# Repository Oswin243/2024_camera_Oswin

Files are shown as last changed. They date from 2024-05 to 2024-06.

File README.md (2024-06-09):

# 2024_camera_Oswin
## Vidéo 

https://github.com/Oswin243/2024_camera_Oswin/assets/166718391/0ddc3cbc-4c59-40dc-9dcf-1f61af386e99

### Table de matie des matières
 [lien fabricaton PCB](https://oshwlab.com/oswin03/sch-ma-cam-ra) 

- [Introduction](#Introduction)
- [Le schéma bloc](#Le-schéma-bloc) 
- [Les caractéristiques](#Les-caractéristiques)
- [Le schéma de principe de la caméra](#Le-schéma-de-principe-de-la-caméra)
  - [Le routage et sérigraphie du PCB](#Le-routage-et-sérigraphie-du-PCB)
- [Bibliothèques nécessaires](#Bibliothèques-nécessaires)  
- [Partie mécanique](#Partie-mécanique)
- 

## Introduction

Pour le cadre de mon projet de fin d’études, j’ai décidé de concevoir une caméra de surveillance connectée, une idée qui m’est venue après avoir visionné des vidéos sur la chaîne [YouTube de Max Imagination](https://www.youtube.com/watch?v=Ul0h5Maeoeg&t=4s). Cette caméra sera en mesure de se déplacer de haut en bas et de droite à gauche avec à des servomoteurs, de filmer tout ce qui se trouve dans son champ de vision. Elle sera également capable de détecter une intrusion avec à des capteurs infrarouges. De plus, la caméra pourra réagir aux mouvements dans son champ de vision, de jour comme de nuit, grâce à des LED infrarouges.
Ce projet représente ma passion pour la technologie et mon engagement envers ce domaine. 
J’ai choisi ce projet par passion pour la technologie de surveillance et les robots.
Ce projet reflète ma passion pour la technologie de surveillance, les robots, et la mécanique, ainsi que mon engagement envers ces domaines. Tout au long de mon parcours scolaire, j’ai acquis des connaissances solides dans ces domaines et j’ai su démontrer ma capacité à résoudre des problèmes.
C’est avec plaisir que je choisis ce projet, car il représente pour moi la fin d’un long parcours scolaire.

## Le schéma bloc



Explication du schéma bloc 

Alimentation : l’alimentation est l’élément vital de l’ensemble du projet, fournissant l’énergie nécessaire à son fonctionnement.

Capteur infrarouge, gauche, droite : capte les mouvements dans son champ d’action, à gauche et à droite.

PCF8574 : Apporte des entrées supplémentaires. 

ESP32 : le « cerveau » du système, l’ESP32 traite, transmet et reçoit toutes les informations nécessaires au fonctionnement du programme.

Smartphone : permets de visualiser le flux vidéo grâce à une connexion Wi-Fi.

PCA9685 : Apporte des sorties supplémentaire et genre nativement du PWM.

LED rouge : indique l’activité de la caméra, signalant ainsi son fonctionnement.

LED infrarouge, gauche, droite : émettre des infrarouges pour voir dans l’obscurité.

Servomoteur x, y : ils permettent d’effectuer des rotations de haut en bas et de gauche à droite, contrôlant ainsi la direction de la caméra

## Les caractéristiques

Caractéristique générale   

•	M5Stack ESP32 Timer Camera 
•	Capteur infrarouge
•	Servomoteurs   
•	LED infrarouge 
•	Resistance 
•	Condensateur 
•	LED 
•	Interrupteur 
•	Transistor
•	Porte fusible   
  
Caractéristique électrique

•	Alimentation : sur secteur  
•	Consommation : pas vérifié  
 
Caractéristique mécanique 

•	Dimension : 218 mm x  238,99 mm  
•	Poids : 851 g 
•	Matériau : PLA (acide polylactique) 

## Le schéma de principe de la caméra



M5stack timer-caméra/ Transistor BS170 /Servomoteur MG996r/ PCF8574/ PCA9685

## Le routage et sérigraphie du PCB

   

[Lien du schéma vers EasyEDA](https://oshwlab.com/oswin03/sch-ma-cam-ra) 

60 mm x 60 mm

## Bibliothèques nécessaires 

Bibliothèques nécessaires pour intégrer les microcontrôleurs ESP32 : 
https://m5stack.oss-cn-shenzhen.aliyuncs.com/resource/arduino/package_m5stack_index.json                                                                               https://raw.githubusercontent.com/espressif/arduino-esp32/gh-pages/package_esp32_index.json 

## Partie mécanique





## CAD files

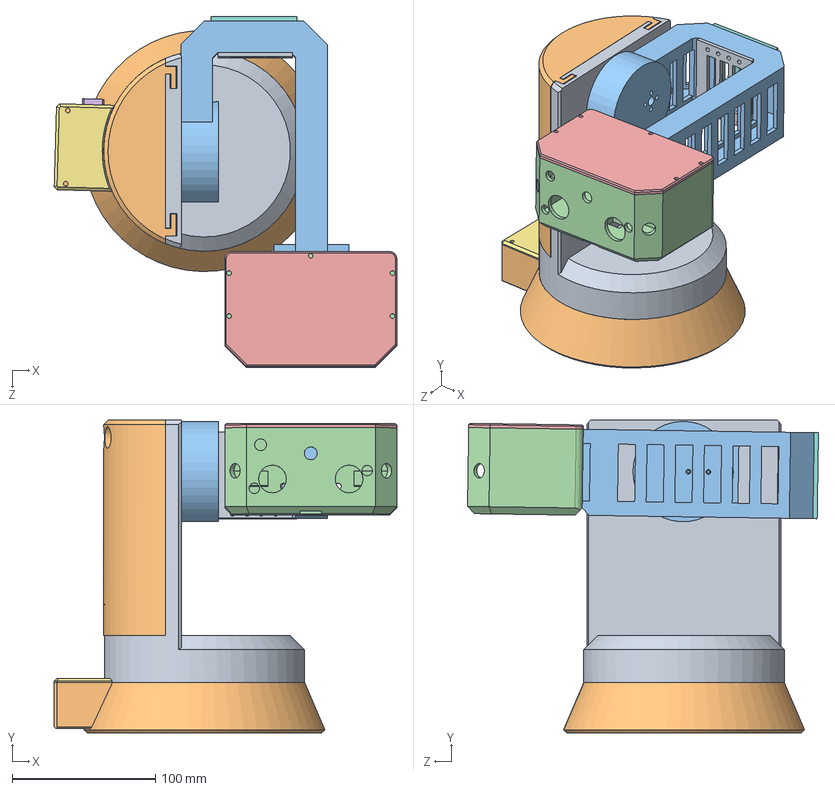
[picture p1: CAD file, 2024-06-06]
Dessin technique/Assemblage_1.SLDASM
239.0 x 218.0 x 244.8 mm
Pièce de haut corrigé
Base caméra
User Library-Futaba-Parallax-ContinuousRatationServo x 2
User Library-Futaba-Servo-X-Horn x 2
PCB caméra (seulement carte)
Connecteur JST-4P
Connecteur JST-3P
Connecteur JST-2P
Connecteur JST-3P - Copie (0)
Connecteur JST-3P - Copie (2)
Connecteur JST-3P - Copie (3)
Connecteur JST-3P - Copie (4)
Connecteur JST-3P - Copie (5)
Connecteur JST-3P - Copie (6)
Connecteur JST-3P - Copie (7)
Connecteur JST-3P - Copie (8)
Connecteur JST-3P - Copie (9)
Connecteur JST-2P - Copie (0)
Connecteur JST-2P - Copie (1)
Condensateur 10v 1000uf
Transistor
Transistor - Copie (0)
Transistor - Copie (1)
User Library-RES_1206L_RES_1206_Lead_1_Default_1 x 6
User Library-RES_1206L_RES_1206_Body_1_1 x 3
Couverture PCB corrigé
boite camera corrigé
tête camera corrigé
couverture camera
cache USB
couverture alimentation
couverture 1
couverture 2

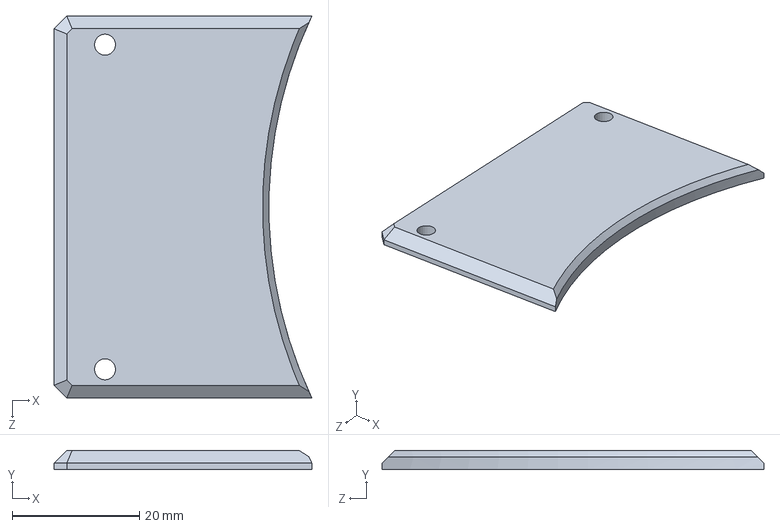
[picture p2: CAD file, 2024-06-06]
Dessin technique/couverture alimentation.SLDPRT
40.5 x 3.00 x 60.0 mm

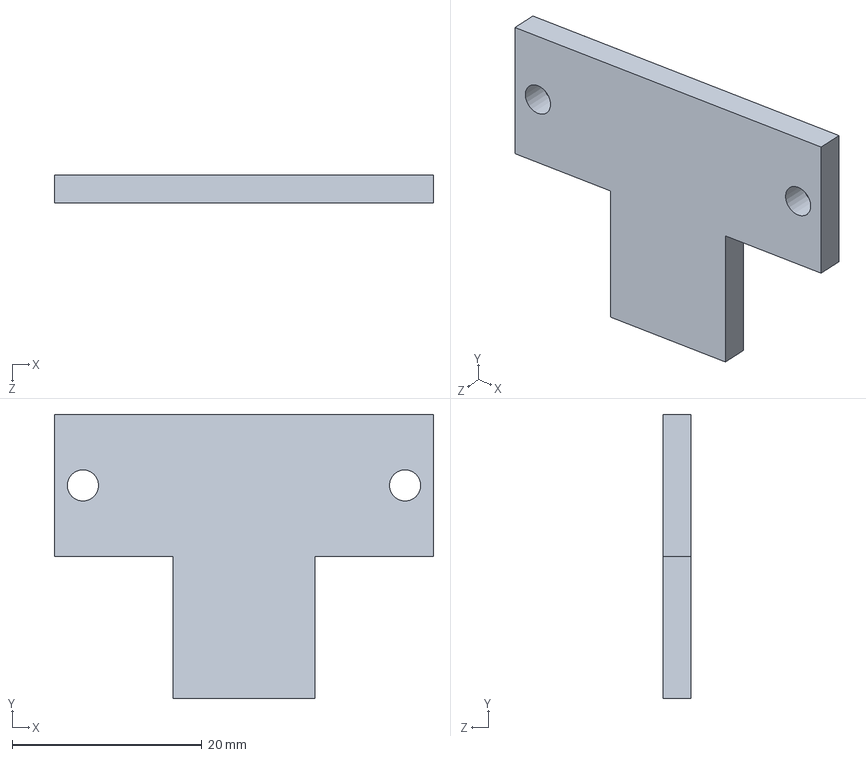
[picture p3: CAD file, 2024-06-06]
Dessin technique/cache caméra.SLDPRT
40.0 x 30.0 x 3.00 mm

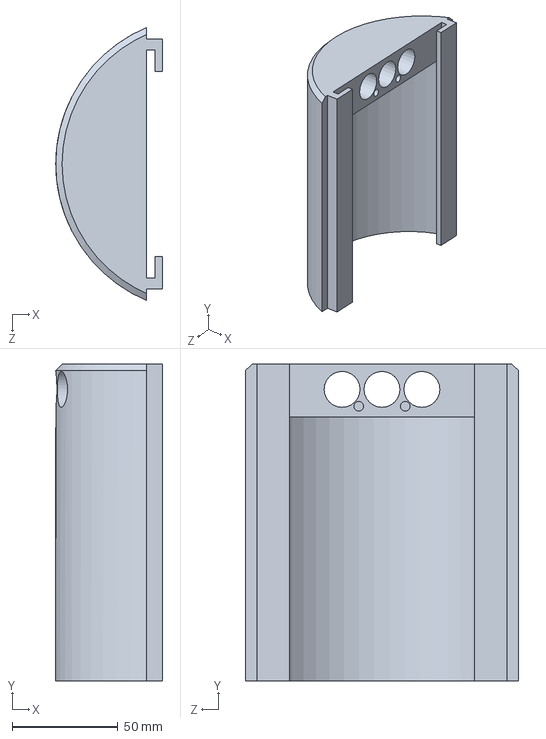
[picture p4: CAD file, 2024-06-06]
Dessin technique/Couverture PCB 1.SLDPRT
50.4 x 150.0 x 129.2 mm

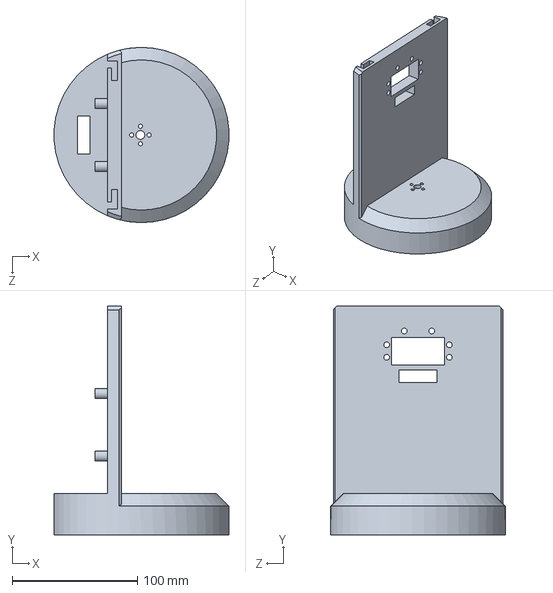
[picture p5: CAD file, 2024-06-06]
Dessin technique/Pièce de haut 1.SLDPRT
139.7 x 183.0 x 140.0 mm

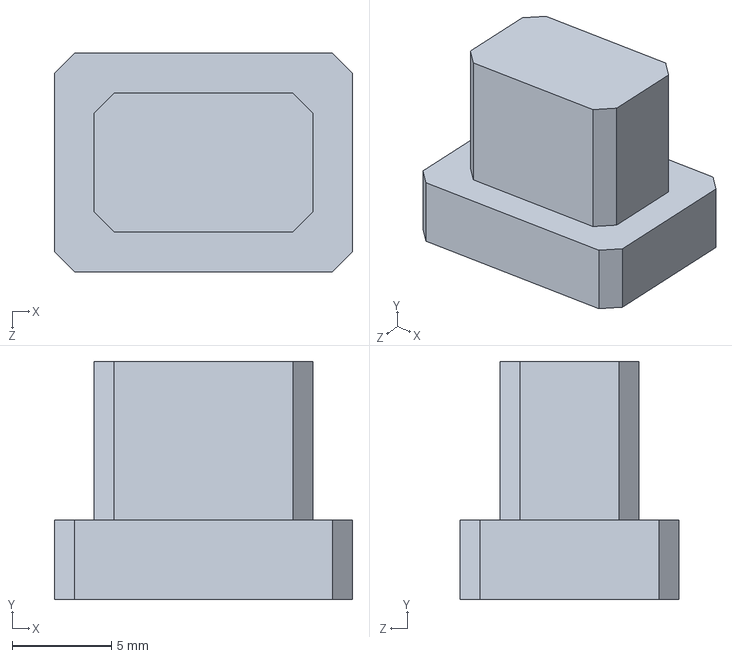
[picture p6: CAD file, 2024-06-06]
Dessin technique/Bouchon.SLDPRT
15.0 x 12.0 x 11.0 mm

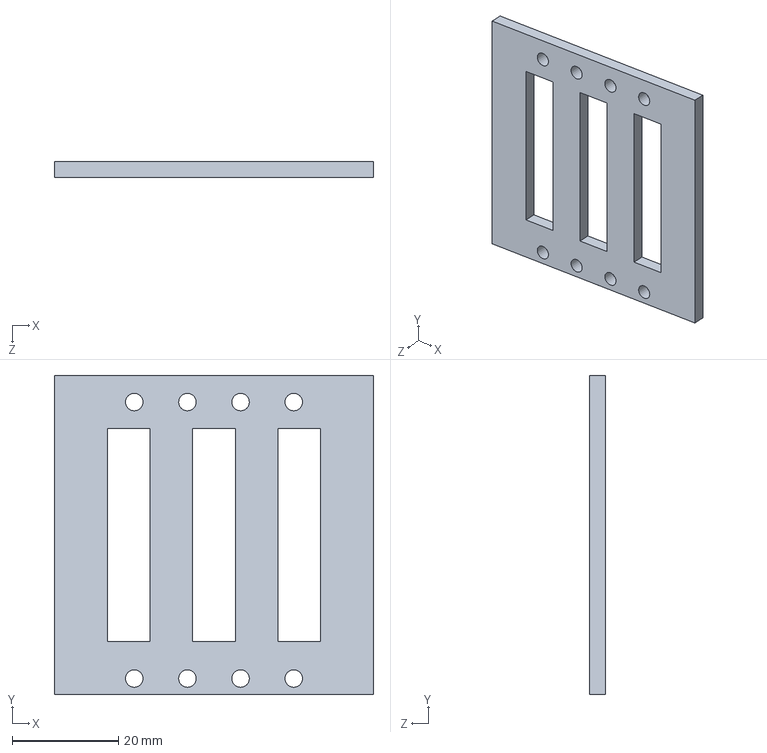
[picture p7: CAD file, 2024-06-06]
Dessin technique/couverture 1.SLDPRT
60.0 x 60.0 x 3.00 mm

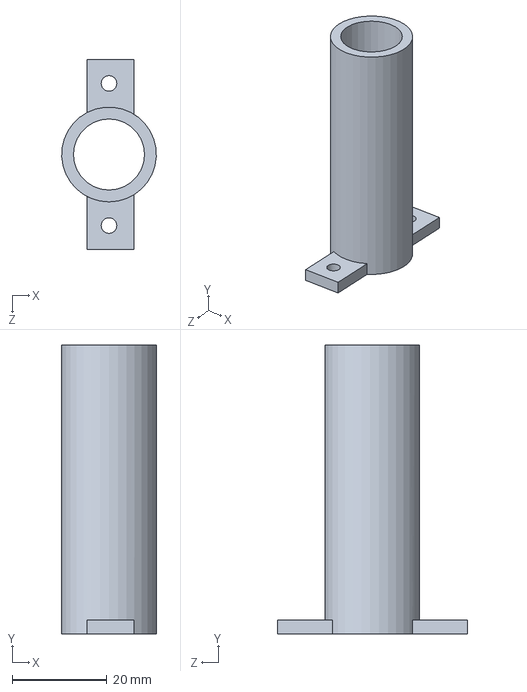
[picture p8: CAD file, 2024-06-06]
Dessin technique/oeillères.SLDPRT
20.0 x 61.0 x 40.0 mm

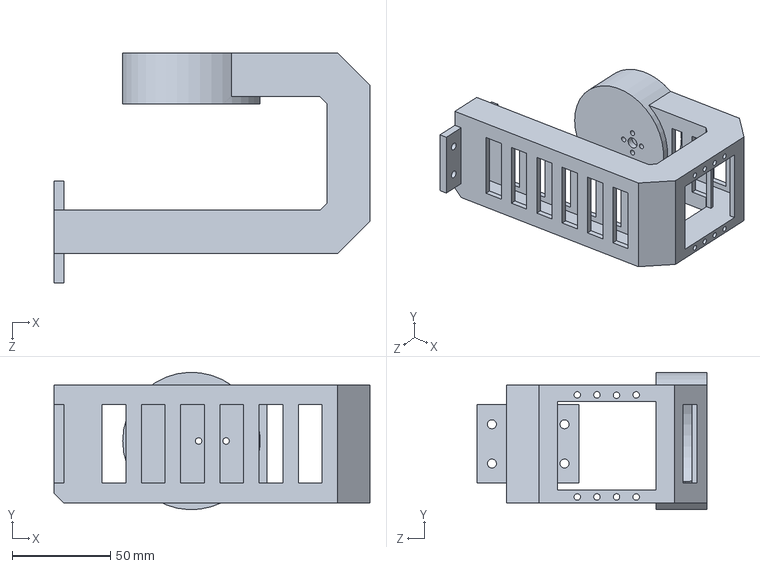
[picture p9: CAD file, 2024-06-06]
Dessin technique/boite camera 1.SLDPRT
161.0 x 69.9 x 117.0 mm

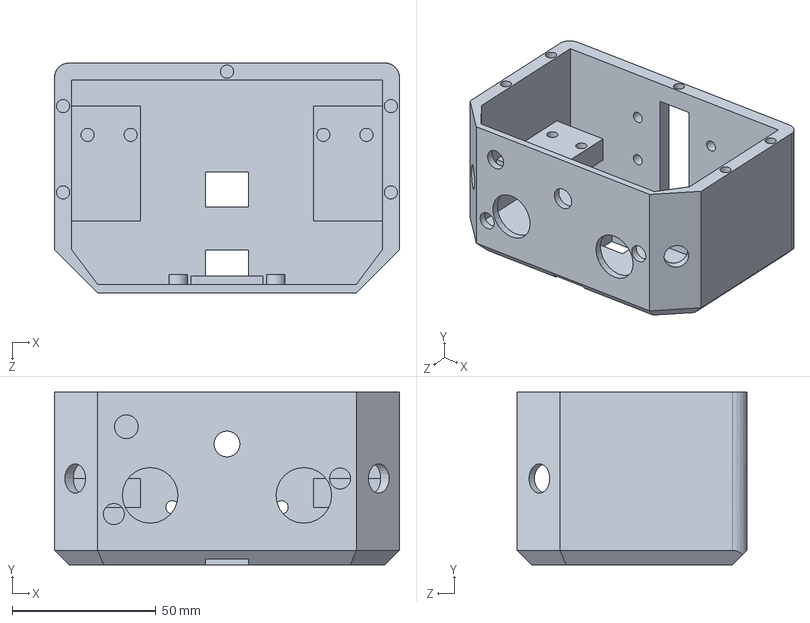
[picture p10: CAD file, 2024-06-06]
Dessin technique/tête camera 1.SLDPRT
120.0 x 60.0 x 80.0 mm

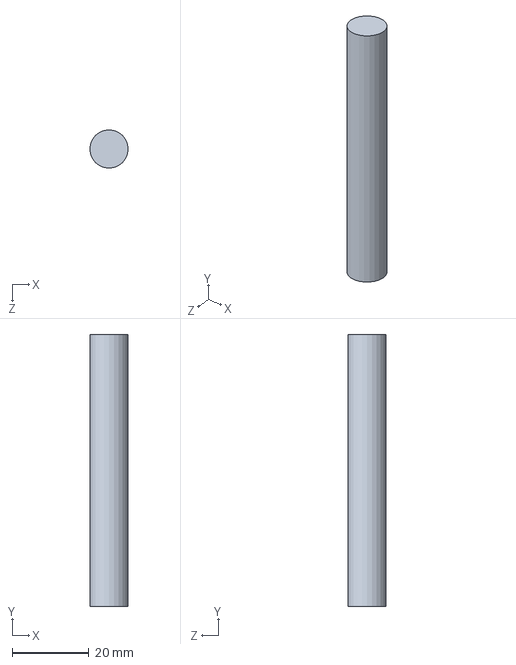
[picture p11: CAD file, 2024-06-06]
Dessin technique/Support led_infra.SLDPRT
10.0 x 71.0 x 10.0 mm

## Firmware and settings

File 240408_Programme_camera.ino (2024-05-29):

/*****************************************Caméra*****************************************
 Caméra connectée
 Kanema Oswin 
 6ème Electronique Inraci (Institut national de radioélectricité et cinématographie)
 Hardware: M5Stack-Timer-CAM; visionnage + PCA9685; i2c (pwm) entrées/sorties supplémentaire + PCF8574 entrées/sorties supplémentaire + servomoteur mg996r
 
*****************************************librairies**************************************/

#include "esp_camera.h"
#include <WiFi.h>
#include <Wire.h>
#include "FaBoPWM_PCA9685.h"
#include "Arduino.h"
#include "PCF8575.h"
#define CAMERA_MODEL_M5STACK_UNITCAM  // ne peut être deplacé
#include "camera_pins.h"

/*****************************************Constante**************************************/
//#define CAMERA_MODEL_M5STACK_UNITCAM
#define P0 0
#define P1 1
#define MAX_VALUE 480
#define MIN_VALUE 80
#define MIN_ANGLE 0    // Angle minimum (en degrés)
#define MAX_ANGLE 180  // Angle maximum (en degrés)
PCF8575 pcf8575(0x20);

/*****************************************Variable**************************************/

FaBoPWM faboPWM;
esp_timer_handle_t timer;
unsigned long timeElapsed;
//const char *ssid     = "KAIROS";
//const char *password = "0487371190";
//const char *ssid     = "INRACI_4G";
//const char *password = "Students-INRaCi";
const char* ssid = "#LaboD5";  //ok
const char* password = "0123456789";
//const char* ssid = "Wifi1";
//const char* password = "6qp7W7n2FEtT";
//const char *ssid     = "iPhone de Oswin";
//const char *password = "Dragon200";
int angle_actuel = 90;
int pulseWidth;

/*****************************************Fonctions***************************************/
void setupLedFlash(int pin);
void startCameraServer();
void IRAM_ATTR onTimer(void* param) {
  static int cpt = 0;
}
int calcul_signal(int angle) {
  return (angle * (MAX_VALUE - MIN_VALUE) / MAX_ANGLE) + MIN_VALUE;  // Calcul de la largeur d'impulsion PWM
}

/*****************************************Intialisation***********************************/
void setup() {
  Wire.begin();
  Serial.begin(115200);
  Serial.setDebugOutput(true);
  Serial.println();
  pcf8575.pinMode(P0, INPUT);
  pcf8575.pinMode(P1, INPUT);
  pcf8575.begin();
  if (faboPWM.begin()) {  // vérification
    Serial.println("Find PCA9685");
    faboPWM.init(300);
  }
  faboPWM.set_hz(50);

  camera_config_t config;
  config.ledc_channel = LEDC_CHANNEL_0;
  config.ledc_timer = LEDC_TIMER_0;
  config.pin_d0 = Y2_GPIO_NUM;
  config.pin_d1 = Y3_GPIO_NUM;
  config.pin_d2 = Y4_GPIO_NUM;
  config.pin_d3 = Y5_GPIO_NUM;
  config.pin_d4 = Y6_GPIO_NUM;
  config.pin_d5 = Y7_GPIO_NUM;
  config.pin_d6 = Y8_GPIO_NUM;
  config.pin_d7 = Y9_GPIO_NUM;
  config.pin_xclk = XCLK_GPIO_NUM;
  config.pin_pclk = PCLK_GPIO_NUM;
  config.pin_vsync = VSYNC_GPIO_NUM;
  config.pin_href = HREF_GPIO_NUM;
  config.pin_sccb_sda = SIOD_GPIO_NUM;
  config.pin_sccb_scl = SIOC_GPIO_NUM;
  config.pin_pwdn = PWDN_GPIO_NUM;
  config.pin_reset = RESET_GPIO_NUM;
  config.xclk_freq_hz = 20000000;
  config.frame_size = FRAMESIZE_UXGA;
  config.pixel_format = PIXFORMAT_JPEG;
  config.grab_mode = CAMERA_GRAB_WHEN_EMPTY;
  config.fb_location = CAMERA_FB_IN_PSRAM;
  config.jpeg_quality = 12;
  config.fb_count = 1;

  if (config.pixel_format == PIXFORMAT_JPEG) {
    if (psramFound()) {
      config.jpeg_quality = 10;
      config.fb_count = 2;
      config.grab_mode = CAMERA_GRAB_LATEST;
    } else {
      config.frame_size = FRAMESIZE_SVGA;
      config.fb_location = CAMERA_FB_IN_DRAM;
    }
  } else {
    config.frame_size = FRAMESIZE_240X240;
#if CONFIG_IDF_TARGET_ESP32S3
    config.fb_count = 2;
#endif
  }

#if defined(CAMERA_MODEL_ESP_EYE)
  pinMode(13, INPUT_PULLUP);
  pinMode(14, INPUT_PULLUP);
#endif

  esp_err_t err = esp_camera_init(&config);
  if (err != ESP_OK) {
    Serial.printf("Camera init failed with error 0x%x", err);
    return;
  }

  sensor_t* s = esp_camera_sensor_get();
  if (s->id.PID == OV3660_PID) {
    s->set_vflip(s, 1);
    s->set_brightness(s, 1);
    s->set_saturation(s, -2);
  }
  if (config.pixel_format == PIXFORMAT_JPEG) {
    s->set_framesize(s, FRAMESIZE_QVGA);
  }

#if defined(CAMERA_MODEL_M5STACK_WIDE) || defined(CAMERA_MODEL_M5STACK_ESP32CAM)
  s->set_vflip(s, 1);
  s->set_hmirror(s, 1);
#endif

#if defined(CAMERA_MODEL_ESP32S3_EYE)
  s->set_vflip(s, 1);
#endif

#if defined(LED_GPIO_NUM)
  setupLedFlash(LED_GPIO_NUM);
#endif

  WiFi.begin(ssid, password);
  WiFi.setSleep(false);

  while (WiFi.status() != WL_CONNECTED) {
    delay(500);
    Serial.print(".");
  }
  Serial.println("");
  Serial.println("WiFi connected");

  startCameraServer();

  Serial.print("Camera Ready! Use 'http://");
  Serial.print(WiFi.localIP());
  Serial.println("' to connect");
  int angle = 0;
  int pulseWidth = calcul_signal(angle);
  faboPWM.set_channel_value(0, pulseWidth);  // servomoteur axe Y(haut/bas)
  int ServoX = 90;
  int PWM = calcul_signal(ServoX);
  faboPWM.set_channel_value(1, PWM);  //servomoteur axe X (gauche/droite)

  faboPWM.set_channel_value(1, calcul_signal(angle_actuel));
}
/*****************************************Boucle**************************************/
void loop() {
  faboPWM.set_channel_value(2, 1500);          // led U11
  faboPWM.set_channel_value(3, 4095);          // infra.led  U13
  faboPWM.set_channel_value(4, 4095);          // infra.led  U15
  uint8_t CapteurD = pcf8575.digitalRead(P0);  // P0=U4  capteur infrarouge droite
  uint8_t CapteurG = pcf8575.digitalRead(P1);  // P1=U5  capteur infrarouge gauche
/*
  Serial.print(CapteurG);
  Serial.print("     ");
  Serial.println(CapteurD);
  delay(300);
*/
  if (CapteurD == 1) {
    Serial.println("HUMAIN a droite");
    for (int angle = angle_actuel; angle >= 33; angle--) {
      faboPWM.set_channel_value(1, calcul_signal(angle));  // U9 servomoteur
      delay(80);
    }
    angle_actuel = 33;
  }

  if (CapteurG == 1) {
    Serial.println("HUMAIN a gauche");
    for (int angle = angle_actuel; angle <= 123; angle++) {
      faboPWM.set_channel_value(1, calcul_signal(angle));  // U9 servomoteur
      delay(80);
    }
    angle_actuel = 123;
  }
}

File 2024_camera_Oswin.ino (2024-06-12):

/*****************************************Caméra*****************************************
 Caméra connectée
 Kanema Oswin 
 6ème Electronique Inraci (Institut national de radioélectricité et cinématographie)
 Hardware: M5Stack-Timer-CAM; visionnage + PCA9685; i2c (pwm) entrées/sorties supplémentaires + PCF8574 entrées/sorties supplémentaire + servomoteur mg996r
 
*****************************************librairies**************************************/
#include "2024_camera_Oswin.h"

#define Projet
//#define Test_servomoteur
//#define Test_PCF8574
/*****************************************Variable**************************************/
esp_timer_handle_t timer;
unsigned long timeElapsed;
int angle_actuel = 90;
int pulseWidth;


  
/*****************************************Intialisation***********************************/
void setup() {
  Wire.begin();
  Serial.begin(115200);                          // vitesse de bit par seconde 
  Serial.setDebugOutput(true);
  Serial.println();
  init_PCF8575();
  init_PCA9685();
  init_Camera();
  allumage_LED();
  init_position_axe_x();
  init_position_axe_y();
}
/*****************************************Boucle**************************************/

void loop() {

 #ifdef Projet
  uint8_t CapteurD = pcf8575.digitalRead(P0);  // P0=U4 capteur infrarouge droite  `uint8_t` est un type entier non signé de 8 bits
  uint8_t CapteurG = pcf8575.digitalRead(P1);  // P1=U5 capteur infrarouge gauche

  if (CapteurD == 1) {                      
    if (angle_actuel != 33) {                  // si il est déjà à 33 il ne bouge pas
      Serial.println("HUMAIN à droite");
      for (int angle = angle_actuel; angle >= 33; angle--) { // décrémentation
        faboPWM.set_channel_value(1, calcul_signal(angle));  // U9 servomoteur du bas axe x
        delay(80);
      }
      angle_actuel = 33;
    }
  }

  if (CapteurG == 1) {
    if (angle_actuel != 123) {
      Serial.println("HUMAIN à gauche");
      for (int angle = angle_actuel; angle <= 123; angle++) { // incrémentation
        faboPWM.set_channel_value(1, calcul_signal(angle));  // U9 servomoteur du bas axe x
        delay(80);
      }
      angle_actuel = 123;
    }
  }
#endif

#ifdef Test_PCF8574
  uint8_t etat = pcf8575.digitalRead(P1);
  if (etat == 1) {
    Serial.println(etat);
    delay(1000);
  } else if (etat == 0) {
    Serial.println(etat);
  }
#endif

#ifdef Test_servomoteur
  if (Serial.available() > 0) {   
    String input = Serial.readStringUntil('\n');  
    int angle = input.toInt();                    // Convertir la chaîne en un entier (angle)
    angle = constrain(angle, 0, 180);             
    int pulseWidth = calcul_signal(angle);        // Convertir l'angle en largeur d'impulsion
    faboPWM.set_channel_value(1, pulseWidth);     
    Serial.print("Position du servo mise à jour : "); // Afficher la position du servomoteur mise à jour
    Serial.println(angle);
  }
}
#endif
}

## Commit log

2024-05-23 Version24/05/23
    Corriger avec M.Mazzeo
    [240408_Programme_camera.ino]
2024-05-23 Update 240408_Programme_camera.ino
    Correction du 24/05/23
    [240408_Programme_camera.ino]
2024-06-04 Ajout de la table des matières
2024-06-05 insertion des programmes de test: PCA/PCF
2024-06-06 Ajout des commentaires
2024-06-06 Dessin technique 3D
    [Assemblage_1.SLDASM, Bouchon.SLDPRT, Couverture PCB 1.SLDPRT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]
2024-06-07 problème fonction servo
